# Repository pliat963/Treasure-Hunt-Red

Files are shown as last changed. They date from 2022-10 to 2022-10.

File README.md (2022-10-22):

# Treasure-Hunt-Red

A "treasure hunt" game that aims to encourage playing outside.
The game consists of a treasure-searching device ("hunter"), and one or more treasures.

By: Plia Trabelsi, Yonatan Reches, Noam Reches

# Repository Structure

- UNIT TESTS directory - contains seperate components tests 

- treasure_hunt directory - contains the files of the project: 

  - treasure_hunt/treasures directory - the code for the "treasure" devices
   
  - treasure_hunt/hunter directory - the code for the device that dearches the treasures 
   
   - SECRETS.h - placed at treasure_hunt/hunter, treasure_hunt/treasures/treasure1 and treasure_hunt/treasures/treasure2. 
      contains wifi passwords, to be replaced by the real passwords

- ASSETS directory - contains a paraboic reflector 3d-print file, used for the hunter

- User Interface.pdf - describes how to use the project

- wifi experiments directory - contains the files and ducumentation of attempts to find a good way to calculate distance using Wifi 

# Used Libraries
1. Adafruit SSD1306 by Adafruit, version 2.5.7
2. Adafruit GFX Library by Adafruit, version 1.11.3
3. Adafruit BusIO by Adafruit, version 1.13.2
4. Kalman filter library: https://github.com/bachagas/Kalman (last commit: 2 Oct 2014)
5. From the esp8266 package version 3.0.2:  
   - ESP8266WiFi by Ivan Grokhotkov version 1.0
   - Wire by Arduino version 1.0

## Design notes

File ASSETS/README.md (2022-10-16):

The printed file was taken from: https://www.thingiverse.com/thing:5175884/files

and was modified to look like this:



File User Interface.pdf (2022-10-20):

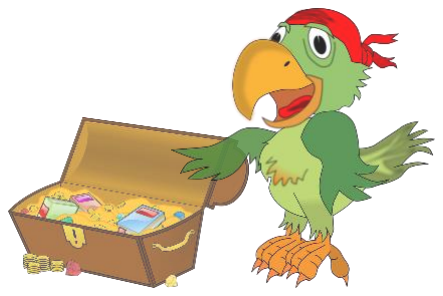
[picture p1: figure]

# חפש את המטמון

## ממשק משתמש

המשחק מורכב משני מטמונים וממחפש. על מנת להתחיל צריך לחבר את המחפש וכמות המטמונים הרצויה לסוללה, לבחור את ההגדרות במחפש, להחביא את המטמונים ולחפשם בהתאם להוראות. על מנת למצוא מטמון צריך לפנות ולהתקדם בכיוון עבורו המספר על מסך המחפש הכי קטן. כאשר מוצאים מטמון ונמצאים קרוב אליו )המספר קטן מ0.4-( יש ללחוץ על כפתור במחפש על מנת לעבור למטמון הבא או לנצח ולסיים את המשחק.

המטמונים

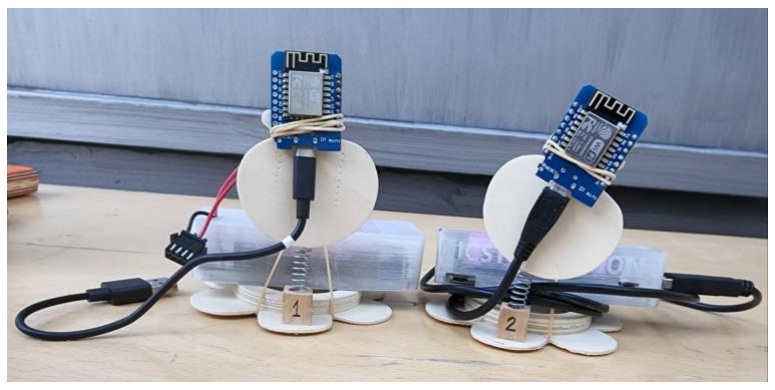
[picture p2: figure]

המשחק כולל שני מטמונים. הם ממוספרים ב1- ו.2- ניתן להשתמש בשניהם או רק באחד מהם )הממוספר ב1-(.
.1 יש לחבר כל אחד מהמטמונים המשתתפים במשחק לסוללה בעזרת כבל USB. .2 יש להחביא אותם, כך שהמטמון הראשון במרחק של לא יותר מ30- מטר )או טווח קליטת Wifi )מנקודת ההתחלה, והמטמון השני )אם הוא בשימוש( במרחק של לא יותר מ30- מטר מהמטמון הראשון.

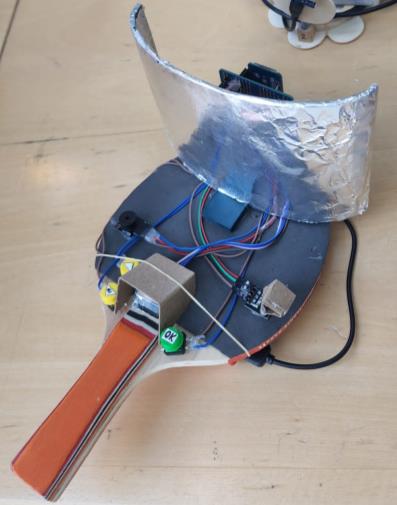
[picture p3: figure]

המחפש

יש לחבר את המחפש לסוללה, ולפעול על פי ההוראות שמופיעות על המסך.
המחפש מורכב משלושה כפתורים, מסך תצוגה, זמזם )באזר(, ונורה.

מסך התצוגה:
* תיאור של המסכים האפשריים המייצגים סטטוסים שונים של המערכת מופיע בעמוד .4 .1 בתחילת המשחק, מאפשר לקבוע פרמטרים של המשחק בעזרת שאלות שמופיעות על גביו בתפריט ההתחלה.
ניתן לדלג על תפריט ההתחלה ולשחק עם פרמטרים שנקבעו מראש )ברירת מחדל(.
* תיאור של הפרמטרים שניתן לקבוע בתפריט ההתחלה מופיע בעמוד .3

.2 במהלך המשחק, מתאר את מצב המשחק הנוכחי: איזה מטמון אנו מחפשים כרגע, במידה ויש טיימר – כמה זמן נותר, ומספר שמייצג הערכה למרחק מהמטמון הנוכחי שמחפשים. מספר קטן יותר מייצג מרחק קצר יותר ו/או כיוון נכון יותר. במידה ויש תקלה עם החיבור ל-Wifi, המסך מציג זאת.

.3 בסוף המשחק, מציג מסך סיום – מסך הצלחה אם כל המטמונים נמצאו )במסגרת הזמן אם יש כזו(, או מסך שאומר שנגמר הזמן, עם הניקוד שהושג עד לנקודה זו. שלושה כפתורים:
.1 כפתור ירוק המסומן ב-"OK": מאפשר להתחיל את המשחק עם הגדרות ברירת מחדל.
בתפריט ההתחלה, משמש לאישור בחירת האפשרות הרצויה לכל אחד מהפרמטרים של המשחק.
במהלך המשחק, יש ללחוץ על כפתור זה כאשר מגיעים מספיק קרוב למטמון )כאשר המספר שמופיע בתצוגה קטן מ0.4-(.

.2 כפתור המסומן בחץ כלפי מעלה:

מאפשר להיכנס לתפריט ההתחלה ולשנות הגדרות לפני תחילת המשחק. בתפריט ההתחלה, מאפשר לעבור לאפשרות הבאה לבחירה.

.3 כפתור המסומן בחץ כלפי מטה וברמקול:

בתפריט ההתחלה, מאפשר לעבור לאפשרות הקודמת לבחירה. במהלך המשחק, מאפשר להשתיק או להפעיל את הזמזם.

זמזם:
במהלך המשחק, מצפצף בקצב גבוה יותר ככל שקרובים יותר למטמון – ישנן חמש "רמות קרבה" שבהתאם להן קצב הצפצוף משתנה: כאשר המספר המופיע על המסך קטן מ,0.4- בין 0.4 ל,2- בין 2 ל5- ובין 5 ל10- הקצב משתנה בהתאם )מהיר יותר ככל שקרובים יותר(, ועבור מספר גדול מ10- אין צפצוף. בנוסף, הזמזם משמיע קולות שמלווים את המשחק - מצפצף כשהמשחק עומד להתחיל, כשמוצאים מטמון, כשנגמר הזמן או כשיש תקלה, וכשמנצחים. נורה:
מהבהבת באדום, כתום וירוק כשהמשחק עומד להתחיל.
במהלך המשחק, מהבהבת באדום כאשר יש תקלה עם החיבור ל-Wifi, מהבהבת בירוק כאשר קרובים למטמון, ומהבהבת בירוק בקצב מהיר יותר כאשר ממש קרובים למטמון וצריך ללחוץ על הכפתור "OK".

הפרמטרים שניתן לקבוע בתפריט ההתחלה:

.1 מספר המטמונים במשחק – כמה מטמונים יש לחפש במהלך המשחק, לפי הסדר שלהם. ערכים אפשריים: 1 או .2
.2 האם להשתמש בטיימר או לא – האם יש מגבלת זמן למשחק. ערכים אפשריים: כן או לא.
.3 במידה ומשתמשים בטיימר, מה מגבלת הזמן. ערכים אפשריים: ,2 4 או 6 דקות.

במשחק עם פרמטרים שנקבעו מראש )ברירת מחדל(: מספר האוצרות הוא ,1 ויש טיימר של 4 דקות. *ראו "פרמטרים שניתן לקבוע ישירות בקוד" למטה.

פרמטר שניתן לקבוע במהלך המשחק:

.1 האם להשתמש בזמזם או להשתיק אותו. כאמור, ניתן לקבוע בעזרת הכפתור המסומן בחץ למטה וברמקול )כפתור 3 לעיל(.

פרמטרים שניתן לקבוע ישירות בקוד:

.1 ניתן לקבוע ישירות בקוד את הפרמטרים הנבחרים כברירת מחדל, במשחק עם פרמטרים שנקבעו מראש. הפרמטרים שניתן לבחור: מספר המטמונים, האם להשתמש בטיימר, אם כן כמה זמן, והאם להשתמש בשמע )ניתן לשנות במהלך המשחק(. השינוי מתבצע על ידי עריכת הקובץ h.PARAMETERS_DEFAULT (https://github.com/pliat963/Treasure-Hunt-Red/blob/main/treasure_hunt/hunter/DEFAULT_PARAMETERS.h) על פי ההנחיות המופיעות בו, וצריבה מחדש של הקוד במחפש.

.2 ניתן לשנות את מספר המטמונים המקסימלי , ומתוכם מספר המטמונים הפעילים, במשחק עם פרמטרים שנקבעו מראש. כלומר, ניתן להוסיף מטמון/ים למשחק. מטמון נוסף יכול להיות למשל פלאפון עם נקודה חמה מופעלת. פרטים נוספים כאן. (https://github.com/pliat963/Treasure-Hunt-Red/wiki/2.-Adding-Treasures)

## Parameters

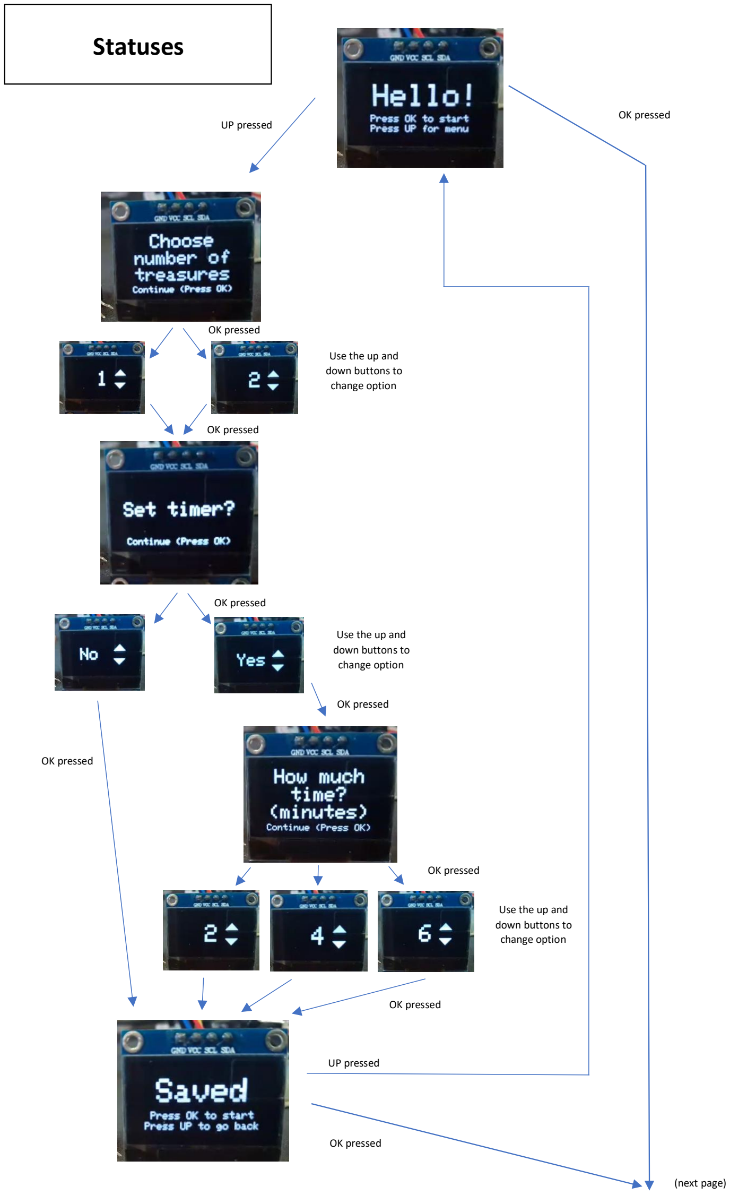
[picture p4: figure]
Statuses:; Use the up and down buttons to change option; Statuses; UP pressed; OK pressed; (next page)
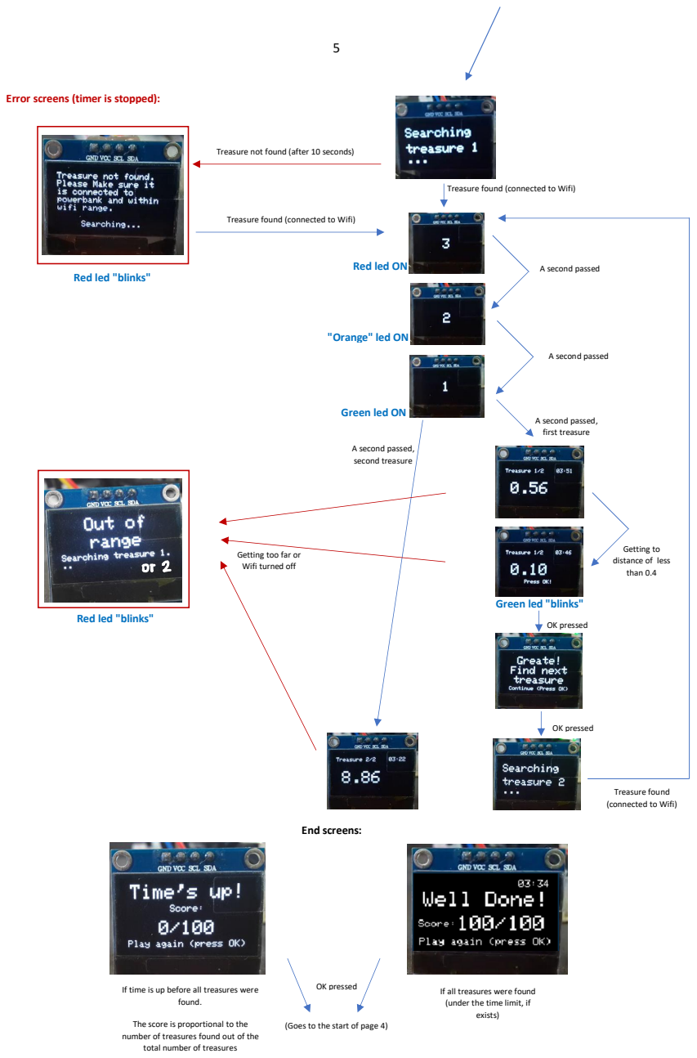
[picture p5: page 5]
exists); found.; End screens:; OK pressed; A second passed; A second passed, second treasure; A second passed, first treasure

Error screens (timer is stopped):

Treasure not found (after 10 seconds)

Treasure found (connected to Wifi)

Red led ON

Red led "blinks"

"Orange" led ON

Green led ON

Getting too far or
Wifi turned off

Getting to
distance of less
than 0.4

Green led "blinks"

Treasure found
(connected to Wifi)

If time is up before all treasures were

If all treasures were found
(under the time limit, if

The score is proportional to the
number of treasures found out of the
total number of treasures

(Goes to the start of page 4)

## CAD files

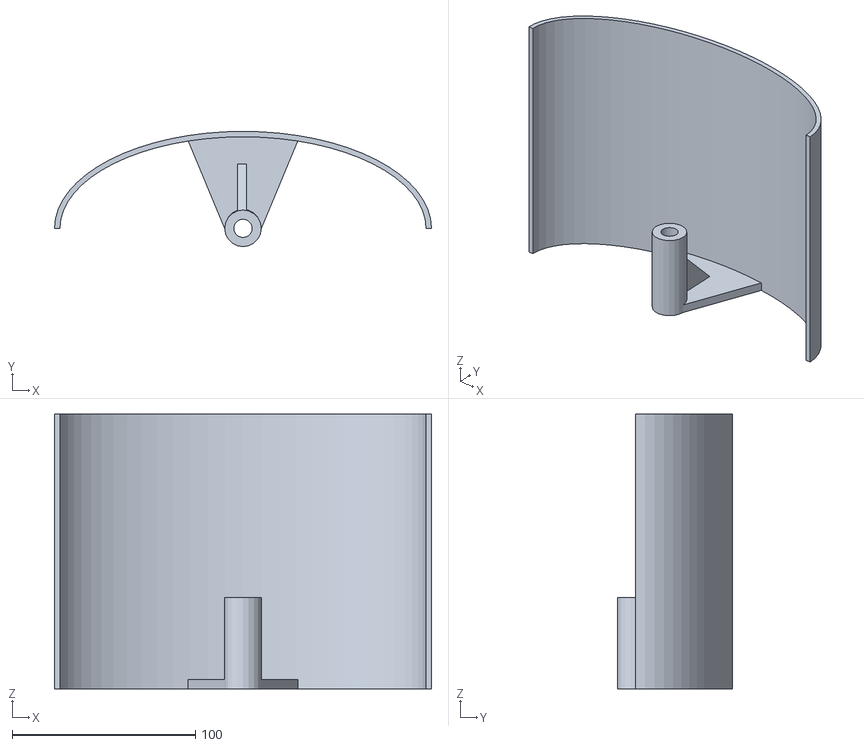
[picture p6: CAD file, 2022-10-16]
ASSETS/parabolic_wifi_extender_for_alfa_antenna1.stl
206.0 x 63.0 x 150.0

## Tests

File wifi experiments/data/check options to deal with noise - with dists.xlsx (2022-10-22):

real distance [cm] | RSSI [dBm] | Kalman filter |  |  | average |  |  |  |  |  |  |  |  | median |  |  |  |  |  |  |  |  | exponential smoothing with alpha equals to: |  |  |  |  |  |  |  |  |  |  |  | moving average (average of last K samples)
a | a |  | calculated distance | error | 10 samples | calculated distance | error | 20 samples | calculated distance | error | 30 samples | calculated distance | error | 10 samples | calculated distance | error | 20 samples | calculated distance | error | 30 samples | calculated distance | error | 0.1 | calculated distance | error | 0.25 | calculated distance | error | 0.5 | calculated distance | error | 0.75 | calculated distance | error | 10 samples | calculated distance | error | 20 samples | calculated distance | error | 30 samples | calculated distance | error | 50 samples | calculated distance | error
 | -68 | -68.48 | 1531.396744 |  |  |  |  |  |  |  |  |  |  |  |  |  |  |  |  |  |  |  | -68 | 1444.855985 |  | -68 | 1444.855985 |  | -68 | 1444.855985 |  | -68 | 1444.855985 |  |  |  |  |  |  |  |  |  |  |  |  |  | 1.9 | n=
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

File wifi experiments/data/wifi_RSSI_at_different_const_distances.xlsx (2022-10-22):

distance (cm) |  | 20 |  | 50 |  | 70 |  | 80 |  | 100 |  | 150 |  | 200 |  | 250 |  | 300 |  | 350 |  | 400 |  | 500 |  | 600 |  | 700 |  | 800
 |  | RSSI (dBm) | filtered RSSI | RSSI (dBm) | filtered RSSI | RSSI (dBm) | filtered RSSI | RSSI (dBm) | filtered RSSI | RSSI (dBm) | filtered RSSI | RSSI (dBm) | filtered RSSI | RSSI (dBm) | filtered RSSI | RSSI (dBm) | filtered RSSI | RSSI (dBm) | filtered RSSI | RSSI (dBm) | filtered RSSI | RSSI (dBm) | filtered RSSI | RSSI (dBm) | filtered RSSI | RSSI (dBm) | filtered RSSI | RSSI (dBm) | filtered RSSI | RSSI (dBm) | filtered RSSI
 |  | -35 | -35 | -51 | -51 | -56 | -56.01 | -57 | -57 | -58 | -58 | -60 | -60 | -70 | -70 | -81 | -81 | -70 | -70 | -76 | -76 | -75 | -75 | -73 | -73 | -77 | -77 | -76 | -76 | -80 | -80
 |  | -35 | -35 | -51 | -51 | -56 | -56.01 | -57 | -57 | -58 | -58 | -60 | -60 | -70 | -70 | -81 | -81 | -70 | -70 | -76 | -76 | -75 | -75 | -73 | -73 | -77 | -77 | -76 | -76 | -80 | -80
 |  | -35 | -35 | -51 | -51 | -56 | -56.01 | -57 | -57 | -58 | -58 | -60 | -60 | -70 | -70 | -81 | -81 | -70 | -70 | -76 | -76 | -75 | -75 | -73 | -73 | -77 | -77 | -76 | -76 | -80 | -80
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

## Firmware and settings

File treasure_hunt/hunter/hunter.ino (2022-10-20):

// connections: (using  board d1 mini)
// display: scl -> D1
// display: sda -> D2
// UP_BTN -> D6 (gpio12)
// DOWN_BTN -> D3 (gpio0) 
//OK_BTN -> D7 (gpio13)
// BUZZER -> D5 (gpio14)
//led: red -> TX (gpio 1)
//led: green -> RX (gpio 3)



#define UP_BTN 12 //D6
#define DOWN_BTN 0 //D3
#define OK_BTN 13 //D7 
#define BUZZER 14 //D5

#define RED 1 //TX
#define GREEN 3 //RX

#include "Game.h"

int currentBtn1State; // variables to read buttons that affects the display ang game
int currentBtn2State;
int currentBtn3State;

Game game;
void setup()
{
  Serial.begin(9600);

  // buttons
  pinMode(UP_BTN, INPUT_PULLUP);
  pinMode(DOWN_BTN, INPUT_PULLUP);
  pinMode(OK_BTN, INPUT_PULLUP);
  // buzzer
  pinMode(BUZZER, OUTPUT);
  //rgb led
  pinMode(RED, OUTPUT);
  pinMode(GREEN, OUTPUT);

  game.runStartGameMenu(); 
  game.connectToWifi();

}

void loop()
{

  game.play_game();
  //here game is over
  if (digitalRead(OK_BTN) == LOW)
  { // start again
    game.startAgain();
  }
  delay(10);
}

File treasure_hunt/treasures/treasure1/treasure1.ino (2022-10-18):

#include <ESP8266WiFi.h>
#include <WiFiClient.h>
#include <ESP8266WebServer.h>
#include "SECRETS.h"


const char *ssid = SSID_1;
const char *password = PASSWORD_1;

ESP8266WebServer server(80);

void setup()
{
  WiFi.softAP(ssid, password);

  Serial.begin(9600); // Starts the serial communication
  server.begin();
  Serial.println("start!");
}

void loop()
{

  server.handleClient();

}

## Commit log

2022-10-13 improve timer, sound and screens
    add option to choose how much time if there is a timer
    enable and disable sound using the DOWN_BTN during the game, instead of at the beginning
    add some screens
2022-10-13 improve game start-and-end options, fix timer bug
    add option to start game with default parameters (and skip menu)
    add option to play again after game is over
    fix timer bug (make sure it doesen't count the time when it is paused)
    [DisplayAnimations.ino, DisplayDrawScreens.ino, Game.h]
2022-10-14 add rgb led and get-ready screen
2022-10-16 add parabolic reflector (3D printed) file
    [parabolic_wifi_extender_for_alfa_antenna1.stl]
2022-10-16 improve start of timer and resume (after paused)
2022-10-16 improve timer, error indications, and success screen animation
    [DisplayAnimations.ino, DisplayDrawScreens.ino, Game.h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]
2022-10-20 replace between buttons' pins
    To make the connections in the final form more convenient
    [hunter.ino]
2022-10-22 add experiments data and code
    [check options to deal with noise - with dists.xlsx, wifi_RSSI_at_different_const_distances.xlsx]
